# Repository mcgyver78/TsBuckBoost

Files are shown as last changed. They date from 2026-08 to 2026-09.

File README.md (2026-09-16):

# Hardware for TsBuckBoost

Printable parts and wiring notes around the Victron Buck-Boost DC-DC converter. This is
a separate branch on purpose: the `latest` branch is installed onto GX devices through
kwindrem's SetupHelper, and these files have no business in that package.

The driver itself is on the [`latest`](../../tree/latest) branch.

## 80 mm fan mount, Buck-Boost 50 A

`fanmount_80mm_BuckBoost50A.step` — parametric source, open it in FreeCAD, Fusion or
anything else that reads STEP.

`fanmount_80mm_BuckBoost50A.stl` — ready to slice.

The converter reduces its output current as it heats up, well before the alarm
thresholds of the driver. A slow 80 mm fan is enough to keep the charge current at its
full value in a closed compartment.

Printed in PETG. PLA is a poor choice here — the mount sits on a device whose case gets
warm by design.

## Fan wiring

`fanwiring_dcssr_BuckBoost.svg` / `.pdf` — how to switch that fan from the converter
itself: pin 2 drives a DC solid state relay, the fan hangs on a fused tap off the
converter's IN or OUT stud, everything on one common ground.

The converter runs 12 V or 24 V on either side, so the drawing leaves both open: take
the supply from the side whose voltage matches the fan. Pin 1 is left alone — it is the
enable input, which the driver reads as /Mode.

Read the notes on the drawing before wiring. The important one: the SSR has to be DC
rated. An AC triac type conducts until the current crosses zero, which on DC never
happens, and the fan would never switch off.

## 92 mm fan mount, Buck-Boost 50 A

`cad/out/fanmount_92mm_BuckBoost50A.step` / `.stl` — the same mount drawn for a
Sunon GF92251B1-000U-AE9. Both sizes are kept on purpose: the 92 mm fan moves the same
air more slowly, and more quietly, wherever there is room for it.

## Cooling hood — a draft, not yet printed

`cad/out/concept_hood.step`, `print_hood.stl`, and `print_spacers_8mm/_10mm/_12mm.stl`.

The converter stands on four loose spacers at its own mounting points. There is
deliberately no base plate: the mounting surface itself is the floor of the lower duct.
The fan presses from above into a plenum over the fins, a duct along the left long side
takes part of that air underneath the device so both sides see flow, and both end faces
blow out. One M5 per corner runs through hood column, converter and spacer in a single
fastening.

Hood 151.9 × 61.0 × 216.0 mm. Print it standing on an end face, in GreenTEC Pro,
annealed — it sits over fins that reach 75 °C and the air inside it is hotter still, so
PLA is out. `print_hood.stl` is already oriented for that; do not rotate it.

Four things are open before this can be released: which side is "left" in the real
installation, whether cables block an end face, whether 61 mm of height fits, and which
spacer height to settle on. All three spacer heights are exported.

## cad/

The CadQuery scripts and the generated STEP/STL under `cad/out`.

The manufacturer's STEP model of the converter is deliberately **not** in here — it is
not ours to pass on. `duct_concept.py` uses it when the file sits next to the script and
falls back to a plain block when it does not. That block has no counterbores, so a
clearance check run without the real model reports the mount posts as colliding when
they do not. `cad/DESIGN-NOTES.md` names the file and says what is measured off it.

`cad/DESIGN-NOTES.md` carries the reasoning: every dimension was measured on that model
with CadQuery rather than taken from a datasheet, what was rejected along the way and
why, and the boolean and watertightness checks that should run before any release. Its
most important finding is that the two sides of the converter are not alike, which is
what decides how anything can be fastened to it.

Those notes are in German, unlike the rest of this repository.

## License

MIT, same as the driver.

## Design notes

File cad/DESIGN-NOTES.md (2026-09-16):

# Kühlhardware für den Buck-Boost 50 A — Entwurfsstand

Stand 16.09.2026. Alles in diesem Ordner ist CAD und gehört auf den Branch
`hardware`, nicht ins SetupHelper-Paket.

Zwei Teile:

* **Lüfterhalter** (`fanmount.py`) — fertig, 80 mm ist committet, 92 mm nicht
* **Kühlhaube** (`duct_concept.py`) — Entwurf, noch nicht gedruckt

---

## Der Converter, ausgemessen

Alle Maße stammen aus dem Herstellermodell
`871efab6-50ABuckBoostDCDCconverterstep.STEP`, nachgemessen mit CadQuery.
Nicht aus Datenblättern, nicht geschätzt.

Die Datei selbst liegt **nicht** im Repo — sie ist nicht unsere, um sie
weiterzugeben, und `.gitignore` hält sie draußen. Wer die Prüfungen unten fahren
will, legt sie neben die Skripte; ohne sie greift der Quader-Ersatz, siehe
„Skripte".

```
Körper      X -96.5 .. 22.5    Y 0 .. 37    Z -109.9 .. 103.2
Bohrbild    X -89.95 / 16.05   Z -103.41 / 96.59
Rippen      2,4 mm hoch, ~4 mm breit, 10 mm Teilung, längs, auf BEIDEN Seiten
```

**Die beiden Seiten sind nicht gleich, und das ist der wichtigste Punkt.**

| | Seite A | Seite B |
|---|---|---|
| Bohrung | ⌀5,52 durchgehend | ⌀5,52 durchgehend |
| drumherum | freie **⌀15,5-Senkung, 22,5 mm tief** unter den Rippenspitzen, gefräste Auflagefläche 2,4 mm unter den Spitzen | plane, gefräste **25,9 mm breite Fläche**, läuft längs durch alle vier Montagepunkte (X −95,9…−70,0 und −4,0…+22,0) |

Im STEP ist Seite A die Y-0-Seite, Seite B die Y-37-Seite.

Die Senkung ist 22,5 mm tief ab Rippenspitze, 20,1 mm ab der Auflagefläche.
**20,1 ist exakt `POST_STEP` im Lüfterhalter** — der ⌀12-Pfosten des Halters
steckt in dieser Senkung, `SCREW_HEAD_Z = 21.6` ist der Schraubenkopf knapp
darüber. Der Lüfterhalter gehört also auf Seite A, und die Kühlhaube auch.

Weiter unten in der Bohrung: ⌀10,8 von 22,5 bis 27,5, dann die ⌀5,52 durch bis
zur anderen Seite.

Gemessene lichte Weite der Senkung je Loch: 15,47 / 15,61 / 15,80 / 15,97 mm.

**Ein Guss-Merkmal neben einem der vier Löcher lässt die Auflagefläche nur bis
⌀16,5 frei.** Deshalb ist die Schulter der Haube ⌀16 und nicht ⌀18 wie beim
Lüfterhalter. Nachgemessen an allen vier Löchern, drei sind bis ⌀26 frei.

---

## Kühlhaube — Aufbau

Der Converter steht auf vier losen Distanzstücken an seinen eigenen
Montagepunkten. Die Montagefläche selbst ist der Boden des unteren Kanals —
eine durchgehende Grundplatte gibt es bewusst nicht, die existiert schon.

Der Lüfter drückt von oben in ein Plenum über den Rippen. Ein Kanal an der
linken Längsseite führt einen Teil der Luft nach unten unter das Gerät, sodass
beide Seiten angeströmt werden. Ausgeblasen wird an den beiden Stirnseiten;
seitlich ist nur links Platz.

Ein M5 je Ecke geht von oben durch Haubensäule, Converter und loses
Distanzstück in die Montagefläche — eine durchgehende Verschraubung.

### Die vier Säulen

Nach dem Vorbild der Pfosten im Lüfterhalter:

```
⌀12 Zapfen, 19,1 mm      in die ⌀15,5-Senkung des Converters
⌀16 Schulter             sitzt auf der gefrästen Fläche, 2,4 mm unter den Spitzen
                         und läuft bis in die Platte
Gesamtlänge              34 mm
```

Der Zapfen endet 1 mm über dem Senkungsgrund. Die Schulter ist damit das
einzige Maß — der Lüfterhalter legt beide auf dasselbe Maß, was zwei Anschläge
gegeneinander arbeiten lässt.

Die Säulen sind **fest Teil der Haube** und werden mit ihr gedruckt. Nur die
Distanzstücke unter dem Converter sind lose. Das war eine ausdrückliche
Festlegung.

**Außer den vier Schultern berührt nichts der Haube den Converter.** Geprüft
gegen das echte, gewendete Herstellermodell: 0,0000 mm³ Kollision, Auflage
340,6 mm² auf den vier gefrästen Flächen.

### Strömungsgeometrie

Der Querschnitt ist ein einziges gezogenes Profil mit Radien, keine Kästen:

```
R12   Plenum knickt in den Seitenkanal ab (Außenseite des Bogens)
R18   Kanal knickt unter den Converter (Außenseite)
R8    Stirnwand läuft nicht in eine rechtwinklige Sackgasse
```

Scharfer Gehrungsbogen kostet rund K = 1,1…1,3 Staudrücke, ein Bogen mit
r/d ≈ 0,7 etwa K = 0,3. Daher die Radien.

Die Lüfterbohrung öffnet sich konisch nach unten (⌀88 → ⌀94 über 4 mm), damit
der Strahl nicht an einer scharfen Kante abreißt.

Plenum **8 mm** über den Rippen. Das ist der Kern: die Rippen sind nur 2,4 mm
hoch, eng heißt also, die Luft läuft an der Oberfläche statt darüber. 5,3 statt
3,5 m/s, h von rund 21 auf 30 W/m²K. Diese 8 mm nicht aufweichen.

Austritte von 8 auf 12 mm über die letzten 30 mm geöffnet, Decke und
Außenfläche steigen gemeinsam an, damit die Platte 4 mm dünn bleibt. Holt
einen Teil des Austrittsstaudrucks zurück.

Die Wände enden 2 mm über der Montagefläche, darunter ein Schaumstreifen —
dichtet und gleicht Unebenheiten aus. Mit 8-mm-Distanzstücken stehen sie auf,
mit 12 mm bleiben 4 mm für den Streifen.

Erwartung: Übertemperatur von rund 30 K auf 18–20 K. Abschätzung nach
Lehrbuchkorrelationen (Dittus-Boelter), die Messung im Betrieb entscheidet.

### Abmessungen

```
Haube        151,9 × 61,0 × 216,0 mm     217,5 cm³
Distanz      ⌀13, in 8 / 10 / 12 mm      3,5 / 4,3 / 5,2 cm³
```

---

## Druck

Drucker: Creality CR-10 V2, 0,4 mm Düse, Cura 5.8.

**Material: GreenTEC Pro, getempert.** Die Haube sitzt über Rippen, die 75 °C
erreichen, die Luft darin ist wärmer. PLA scheidet aus.

**Orientierung: stehend auf einer Stirnseite, 216 mm hoch.** Das gezogene
Profil läuft bereits entlang Z, `print_hood.stl` liegt deshalb schon richtig
auf z = 0 — nichts drehen. In dieser Lage ist der Körper ein konstanter
Querschnitt: alle Wände senkrecht, kein Support, und die Schichtlinien laufen
quer zum Luftweg statt längs. Eine schwache Schicht kann so keinen Leckspalt
den Kanal entlang aufreißen.

Was in der Geometrie schon für den Drucker erledigt ist:

* Wände 3,2 mm = 8 Linien à 0,4. Mit **Wall Line Count = 4** reines Perimeter.
* Flache Auflage (⌀14) um jede Schraube — die Außenfläche ist dort geneigt.
* Waagerechte Löcher 0,2 mm größer, weil ihr Scheitel durchhängt:
  M5 5,8 statt 5,6, Lüfterschrauben 4,7 statt 4,5. Die Distanzstücke stehen
  beim Drucken aufrecht und behalten 5,6.
* Brim nehmen, der Fußabdruck ist ein dünner Ring.

Einziger echter Überhang sind die Säulen, die mit ihrer vollen Länge an der
Platte ansetzen. Liegt innen im Plenum auf Flächen, die nichts berührt. Wer es
sauber will: Support-Blocker über den Rest des Modells, nur die vier Säulen
stützen lassen.

`print_spacers_*.stl` enthält die vier Distanzstücke aufrecht und dicht
beieinander, damit sie als kompakter kleiner Druck laufen.

---

## Was verworfen wurde, und warum

Damit es nicht noch einmal vorgeschlagen wird:

**Zentrierzapfen in die Montagebohrung.** Geht nicht. Die Bohrung ist ⌀5,52 und
der M5 muss durch. Ein Zapfen darin hätte 0,15 mm Wandstärke.

**Durchgehende Grundplatte unter dem Converter.** Ausdrücklich gestrichen — die
Fläche, auf der das Gerät montiert wird, ist schon der Boden.

**Stützkeile neben den Säulen.** Waren als Druckhilfe drin, lagen aber mit
ihrer Unterkante auf y = 37, also direkt auf den Rippen. Damit hätte der
Converter teilweise auf den Keilen gehangen statt an den Schrauben. Raus.

**Zweiter Lüfter, PWM-Regelung.** Ausgeschlossen.

**Plenum aufweiten, um die Säulen zu verlängern.** War ein Zwischenschritt
(`EXIT_RISE` auf 12 mm) und ist wieder raus, seit die Länge aus der Senkung
kommt. Ein größeres Plenum kostet Strömungsgeschwindigkeit und damit genau die
Kühlleistung, um die es geht.

**⌀18-Schulter wie im Lüfterhalter.** Kollidiert an einem Loch mit einem
Gussmerkmal. ⌀16 ist das Maximum.

---

## Offene Punkte

1. **Welche Seite ist „links"?** `SIDE = -1` legt den Kanal auf die −X-Seite,
   das ist die Seite mit den OUT-Bolzen. `SIDE = +1` spiegelt die ganze Haube.
   Vor dem Druck am realen Einbau prüfen.
2. **Ist eine Stirnseite durch Kabel zugestellt?** Dann gehört der Lüfter mit
   `FAN_OFFSET` zur Kanalseite versetzt, damit der untere Weg mehr bekommt.
3. **Bauhöhe über den Stirnseiten** — die Haube ist 61 mm hoch. Passt das im
   Einbau?
4. **Distanzstückhöhe** 8, 10 oder 12 mm ist noch nicht entschieden; 10 mm ist
   der Entwurfswert, alle drei sind exportiert.
5. Der **92-mm-Lüfterhalter** für den Sunon GF92251B1-000U-AE9 ist fertig, aber
   nie auf `hardware` committet worden. Lars wollte beide Größen behalten.
   Das ReadMe auf `hardware` erwähnt bisher nur 80 mm.

---

## Skripte

```
python3 duct_concept.py
python3 fanmount.py 80
python3 fanmount.py 92
python3 detail.py
```

`duct_concept.py` erzeugt Haube und Distanzstücke als STEP und STL,
`fanmount.py` den Lüfterhalter in der als Argument übergebenen Größe,
`detail.py` die Schnittzeichnung des Montagepunkts.

Braucht CadQuery 2.8 (`pip install cadquery`), für `detail.py` matplotlib.

`duct_concept.py` prüft gegen das Herstellermodell, wenn die STEP-Datei
danebenliegt — `converter()` wendet sie um die Längsachse und schiebt das
Bohrbild zurück auf `HOLES`. Ohne die Datei fällt es auf einen Quader zurück,
der die Senkungen **nicht** hat; eine Freigängigkeitsprüfung meldet dann die
Zapfen fälschlich als Kollision.

Beim Wenden **drehen, nicht spiegeln** — eine Spiegelung ergibt das andere
Teil. Das Bohrbild liegt nicht mittig, die Drehung braucht deshalb einen
Versatz von 2 × Mittelwert der Z-Lochkoordinaten.

### Prüfungen, die vor jeder Freigabe laufen sollten

```python
import duct_concept as d, trimesh
h = d.hood()
len(h.val().Solids()) == 1                      # ein Körper
h.intersect(d.converter()).val().Volume() == 0  # gegen das echte Modell
h.intersect(d.spacers(10)).val().Volume() == 0
trimesh.load('print_hood.stl').is_watertight
```

Ein Volumen knapp über null bei den Boolean-Prüfungen heißt fast immer:
zwei Flächen liegen koplanar oder tangential aufeinander. Das erzeugt
Splitterhohlräume im Solid. Lösung ist ein bewusster Überstand von 0,02 mm,
kein Toleranzspiel.

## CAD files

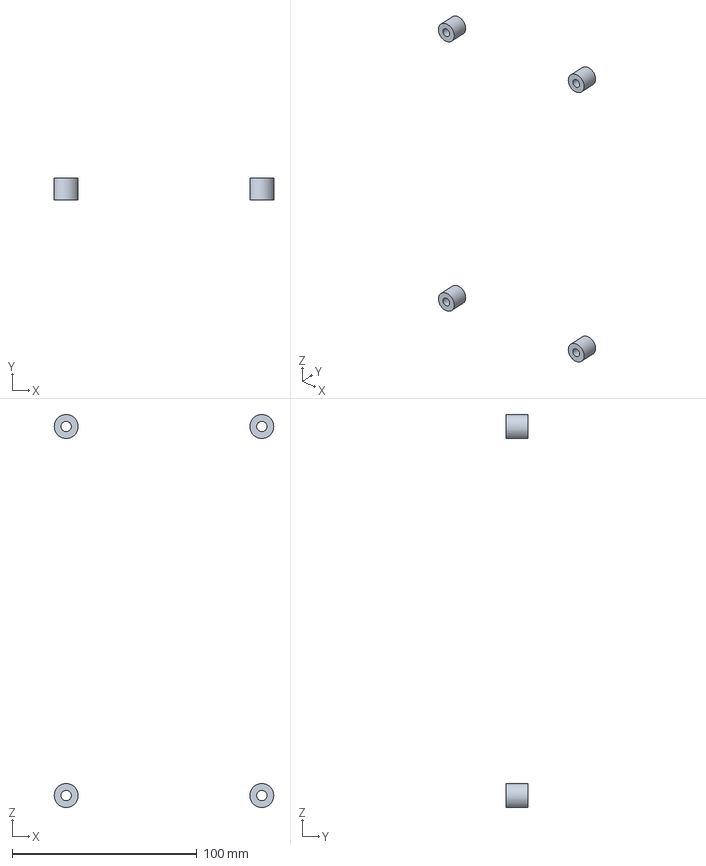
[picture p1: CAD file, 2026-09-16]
cad/out/concept_spacers_12mm.step
119.0 x 12.0 x 213.0 mm

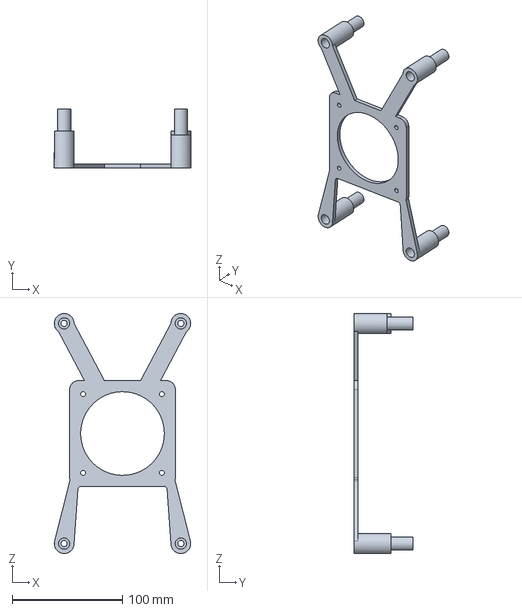
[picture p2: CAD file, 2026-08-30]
fanmount_80mm_BuckBoost50A.step
124.0 x 54.0 x 218.0 mm

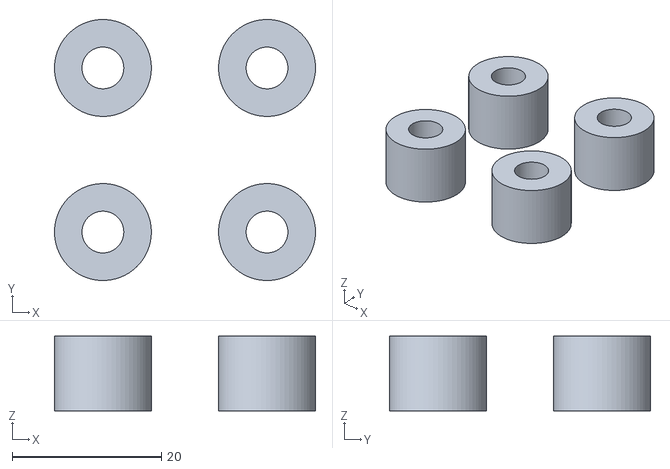
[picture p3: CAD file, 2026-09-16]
cad/out/print_spacers_10mm.stl
35.0 x 35.0 x 10.0

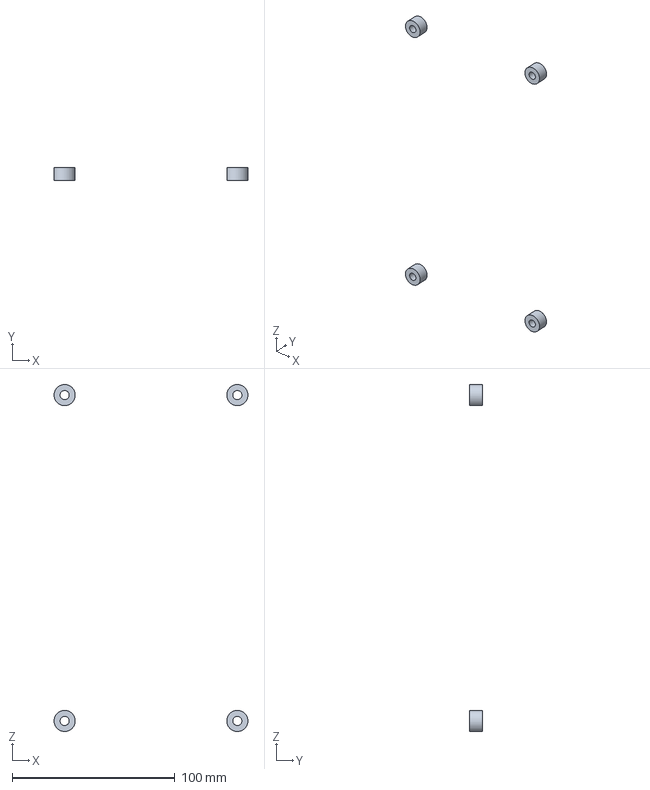
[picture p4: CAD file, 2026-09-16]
cad/out/concept_spacers_8mm.step
119.0 x 8.00 x 213.0 mm

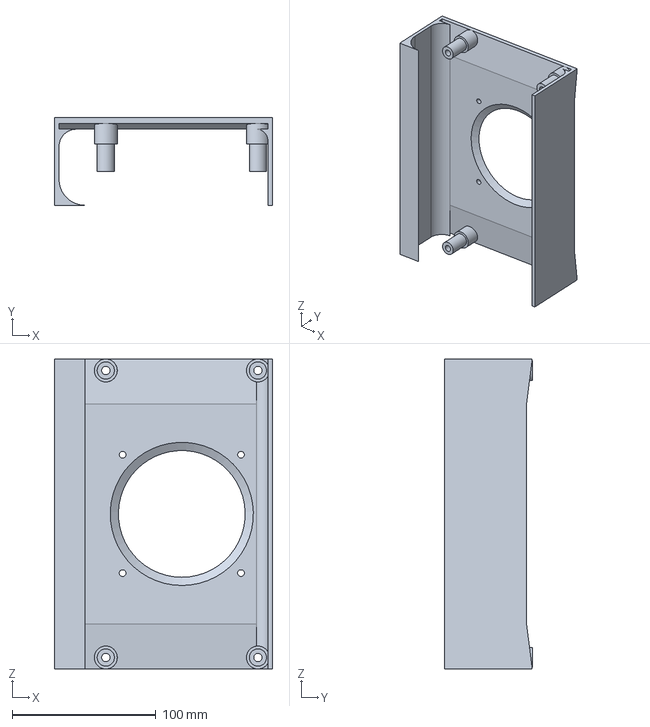
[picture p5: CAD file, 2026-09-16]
cad/out/concept_hood.step
151.9 x 61.0 x 216.0 mm

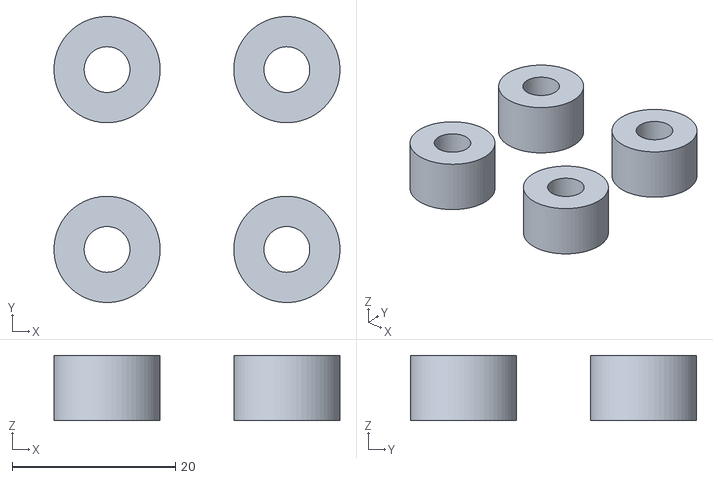
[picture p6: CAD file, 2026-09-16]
cad/out/print_spacers_8mm.stl
35.0 x 35.0 x 8.00

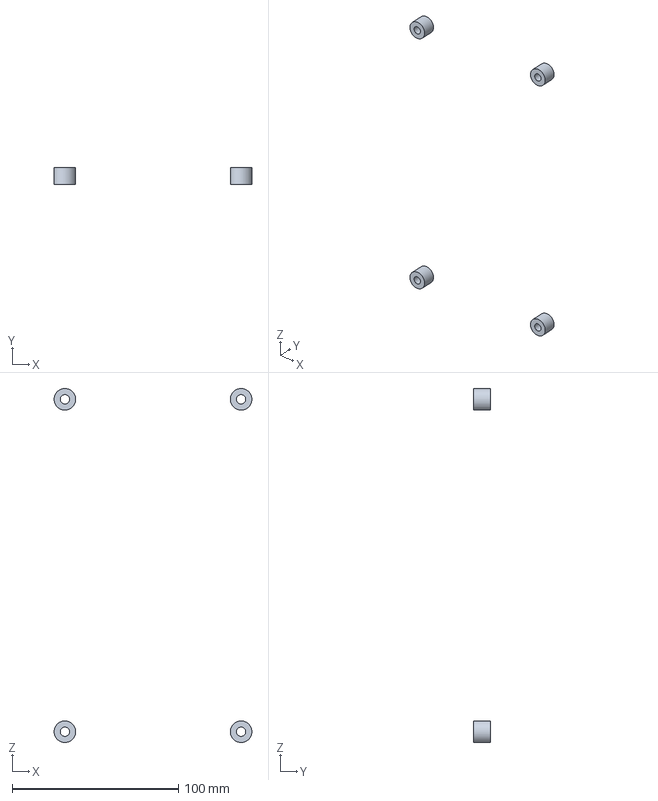
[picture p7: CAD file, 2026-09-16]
cad/out/concept_spacers_10mm.step
119.0 x 10.0 x 213.0 mm

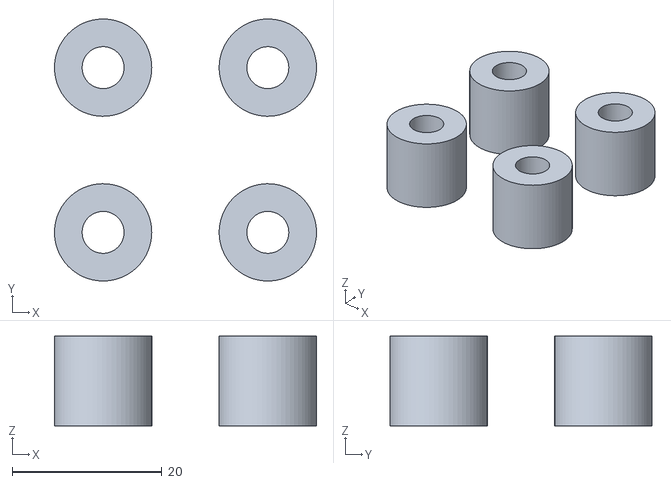
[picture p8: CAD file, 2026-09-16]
cad/out/print_spacers_12mm.stl
35.0 x 35.0 x 12.0

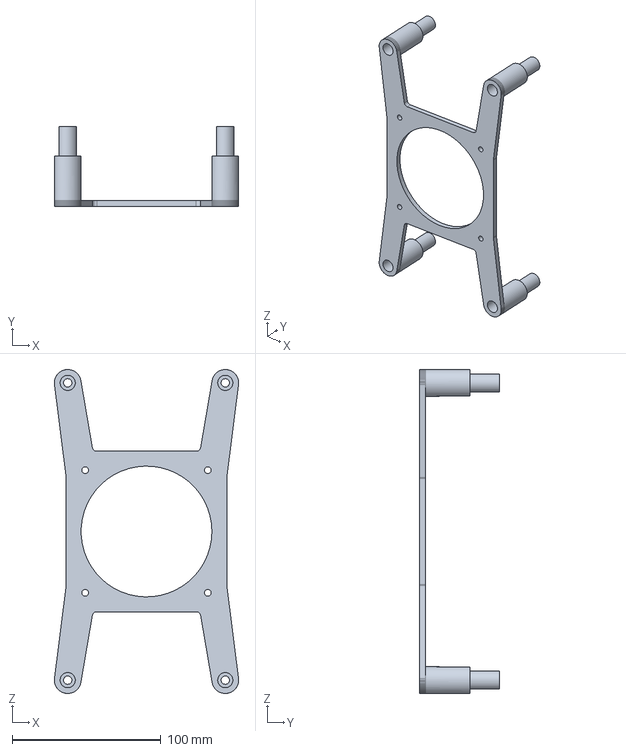
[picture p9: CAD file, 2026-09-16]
cad/out/fanmount_92mm_BuckBoost50A.step
124.0 x 54.0 x 218.0 mm

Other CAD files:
cad/out/print_hood.stl
cad/out/concept_hood.stl
cad/out/fanmount_92mm_BuckBoost50A.stl
fanmount_80mm_BuckBoost50A.stl

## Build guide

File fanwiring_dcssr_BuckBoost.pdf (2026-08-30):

Fan control for the Victron Buck-Boost — switched by the converter output through a DC-SSR

The converter runs 12 V or 24 V on either side. Take the fan supply from the side whose voltage matches the fan.

Installation — all power terminals sit on one end of the case, seen here from that end

P1 pin 1, purple — enable input,
already in use, driver mirrors it as /Mode

P2 pin 2, green — programmable output, function set in TSConfig

## Buck-Boost 25 / 50 / 100 A

IN and OUT each 12 V or 24 V — approx. 207 × 118 × 37 mm

IN | GND | pin 1 · pin 2 | OUT
P1 | P2

V_in A

Alternator | Starter battery 12 V or 24 V

B V_out

House battery
24 V or 12 V

chassis / common ground

Fan branch — supply from tap A or tap B, whichever voltage matches the fan. Connect one of the two, never both.

A

or B | F1

size for the fan

P2

R, old units
DC-SSR — MOSFET or photoMOS, control 3–32 V DC

+

−

Fan, 80 mm
rated for the tapped voltage

same ground as the converter

1 The fan must match the voltage of the tap it hangs on — check which side of your installation is 12 V and which is 24 V before wiring.
2 If the fan does not suit the input side, take the supply from the converter output instead (tap B). Same circuit, other tap.
3 The SSR must be DC rated (MOSFET or photoMOS). An AC triac type conducts until the current crosses zero and never switches DC off again. 4 Pin 2 carries V_in when active and is rated 1.5 A. Old TS units (smooth case) need the series resistor supplied with the converter.

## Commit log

2026-08-30 80 mm fan mount and fan wiring diagram for the Buck-Boost
    [fanmount_80mm_BuckBoost50A.step, fanmount_80mm_BuckBoost50A.stl]
2026-08-30 add fan wiring diagram (SVG/PDF)
2026-09-16 92 mm fan mount and the cooling hood draft, with the measurements behind them
    cad/ holds the CadQuery sources and the generated STEP/STL under cad/out.
    The manufacturer's STEP model of the converter is not in here. Every dimension
    in the notes was measured off it with CadQuery rather than read from a
    datasheet, but the file is not ours to pass on, so .gitignore keeps it out.
    duct_concept.py picks it up when it sits next to the script and falls back to a
    plain block otherwise - a block without the counterbores, which makes a
    clearance check report the mount posts as colliding when they do not. Both the
    notes and the README say so.
    The 92 mm mount for the Sunon GF92251B1-000U-AE9 was finishe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
    [concept_hood.step, concept_hood.stl, concept_spacers_10mm.step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]
2026-09-16 CLAUDE.md: one working tree, and a trap read too widely
    The note about the case-insensitive filesystem warns about copying files
    between branches by hand. It was taken to mean switching branches, and a second
    worktree was built to avoid that. Measured in a throwaway clone instead: git
    switch moves cleanly between ReadMe.md on latest and README.md on hardware,
    both ways, with an empty status afterwards. The worktree is gone again and
    there is one directory.
    Also records that the 92 mm mount and the hood draft are committed now, and
    where the manufacturer model lives: untracked in the working tree, kept out by
    .gitignore on hardware and by .git/info/exclude on latest, which is local to
    this c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
2026-09-18 CLAUDE.md: v1.21, hooks, tests, no battery temperature
